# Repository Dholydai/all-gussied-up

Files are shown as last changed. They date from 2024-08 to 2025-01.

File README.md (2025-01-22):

# all-gussied-up

MAJOR CHANGES HAVE ARRIVED!

This repository will be removed shortly. Most variants have been moved to a new one called writerz-with-an-attitude.

I designed wonderfully sleek cases for my Dvorak 2024. All of my keyboard PCBs have been reworked to fit the new cases... except the TKL

The custom Cherry MX KiCad footprint library used is posted at https://github.com/Dholydai/mx-switch-custom

Please visit https://quixotickeyboards.com for more information.

Ronald Walker

23 Jul 2024 posted the left-hand and right-hand compact files. The trio is completed!

14 Aug 2024 posted the two-hand TKL files.

23 Oct 2024 changed the firmware files for the compact trio. Better edit key layout.

22 Jan 2025 closed out all folders except the TKL variant.

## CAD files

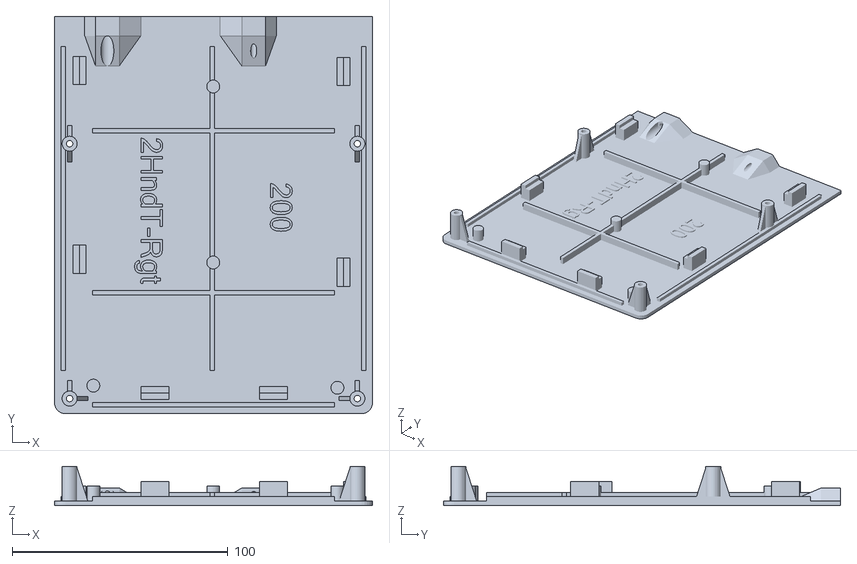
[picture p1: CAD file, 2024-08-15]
TKL2Hand/2HndTKLCase/stl/200ReduxBtmRgt.stl
147.2 x 184.0 x 18.2

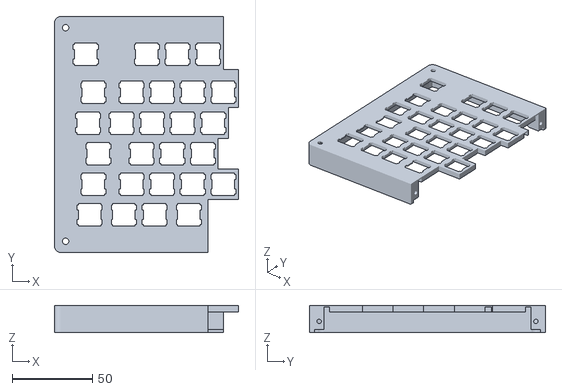
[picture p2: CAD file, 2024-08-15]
TKL2Hand/2HndTKLCase/stl/200ReduxTopLft.stl
114.8 x 147.1 x 17.0

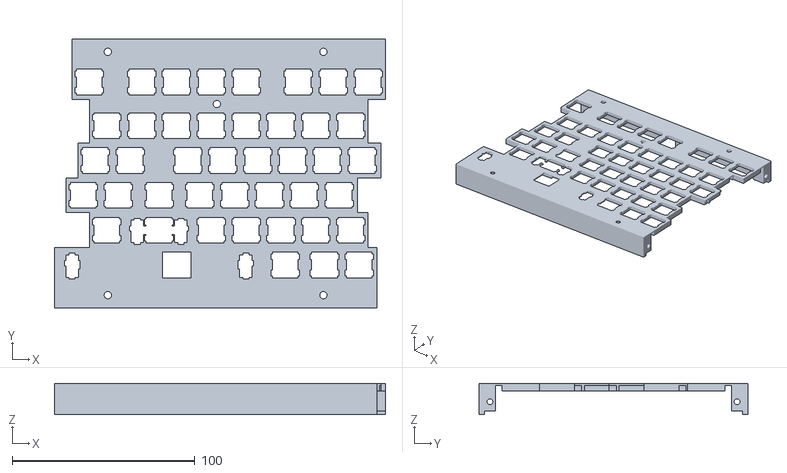
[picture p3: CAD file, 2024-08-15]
TKL2Hand/2HndTKLCase/stl/200ReduxTopMid.stl
181.0 x 147.1 x 17.0

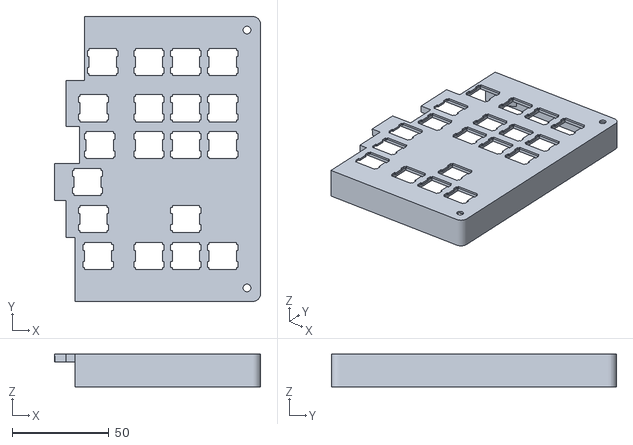
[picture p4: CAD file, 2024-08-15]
TKL2Hand/2HndTKLCase/stl/200ReduxTopRgt.stl
106.4 x 147.1 x 17.0

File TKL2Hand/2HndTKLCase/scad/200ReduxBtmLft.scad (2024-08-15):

//Created by Dholydai on 08 Aug 2024
//TXT
translate([109,62,0])
rotate([0,0,90])
linear_extrude(3)
text("2HndT-Lft",size=10,font="Microsoft Sans Serif");
translate([47,81,0])
rotate([0,0,90])
linear_extrude(3)
text("200",size=10,font="Microsoft Sans Serif");
//BASE
$fn=24;
//Deck and Towers
difference() {
    union() {
        translate([5,5,0])
            cube([137.25,179,2.2]);
        translate([5,0,0])
            cube([137.25,5,2.2]);
        translate([0,5,0])
            cube([5,179,2.2]);
        translate([142.25,5,0])
            cube([5,179,2.2]);    
        translate([5,5,0])
            cylinder(h=2.2,r1=5,r2=5);
        translate([142.25,5,0])
            cylinder(h=2.2,r1=5,r2=5);
        translate([7,7,0])
            cylinder(h=18.2,r1=3.5,r2=3.5);
        translate([7,125,0])
            cylinder(h=18.2,r1=3.5,r2=3.5);
        translate([140.25,125,0])
            cylinder(h=18.2,r1=3.5,r2=3.5);
        translate([140.25,7,0])
            cylinder(h=18.2,r1=3.5,r2=3.5);
    }
    translate([7,7,-4])
        cylinder(d=3,h=26);
    translate([7,125,-4])
        cylinder(d=3,h=26);
    translate([140.25,125,-4])
        cylinder(d=3,h=26);
    translate([140.25,7,-4])
        cylinder(d=3,h=26);
}
//Tower Supports
//Trigon0Y
translate([6,10.4,2.2])
    {TrigonPoints = [
    [0,0,0],//0
    [0,5,0],//1
    [0,0,15.5],//2
    [2,0,0],//3
    [2,5,0],//4
    [2,0,15.5]];//5
    TrigonFaces = [
    [0,1,2],//outside
    [0,3,4,1],//bottom
    [0,2,5,3],//top    
    [2,1,4,5],//back
    [3,5,4]];//inside
polyhedron(TrigonPoints,TrigonFaces);}
//Trigon0Yright
translate([10.4,6,2.2])
    {TrigonPoints = [
    [0,0,0],//0
    [5,0,0],//1
    [0,0,15.5],//2
    [0,2,0],//3
    [5,2,0],//4
    [0,2,15.5]]; //5
    TrigonFaces = [
    [0,2,1],//outside
    [0,1,4,3],//bottom
    [0,3,5,2],//top
    [1,2,5,4],//back
    [3,4,5]];//inside
polyhedron(TrigonPoints,TrigonFaces);}//
//Trigon1Y
translate([6,128.4,2.2])
    {TrigonPoints = [
    [0,0,0],//0
    [0,5,0],//1
    [0,0,15.5],//2
    [2,0,0],//3
    [2,5,0],//4
    [2,0,15.5]];//5
    TrigonFaces = [
    [0,1,2],//outside
    [0,3,4,1],//bottom
    [0,2,5,3],//top
    [2,1,4,5],//back
    [3,5,4]];//inside
polyhedron(TrigonPoints,TrigonFaces);}
//Trigon1Yrev
translate([6,116.6,2.2])
    {TrigonPoints = [
    [0,0,0],//0
    [0,5,0],//1
    [0,5,15.5],//2
    [2,0,0],//3
    [2,5,0],//4
    [2,5,15.5]]; //5
    TrigonFaces = [
    [0,1,2],//outside
    [0,3,4,1],//bottom
    [0,2,5,3],//top
    [1,4,5,2],//back
    [3,5,4]];//inside
polyhedron(TrigonPoints,TrigonFaces);}
//Trigon2Y
translate([139.25,128.4,2.2])
    {TrigonPoints = [
    [0,0,0],//0
    [0,5,0],//1
    [0,0,15.5],//2
    [2,0,0],//3
    [2,5,0],//4
    [2,0,15.5]]; //5
    TrigonFaces = [
    [0,1,2],//outside
    [0,3,4,1],//bottom
    [0,2,5,3],//top
    [2,1,4,5],//back
    [3,5,4]];//inside
polyhedron(TrigonPoints,TrigonFaces);}
//Trigon2Yrev
translate([139.25,116.6,2.2])
    {TrigonPoints = [
    [0,0,0],//0
    [0,5,0],//1
    [0,5,15.5],//2
    [2,0,0],//3
    [2,5,0],//4
    [2,5,15.5]]; //5
    TrigonFaces = [
    [0,1,2],//outside
    [0,3,4,1],//bottom
    [0,2,5,3],//top
    [1,4,5,2],//back
    [3,5,4]];//inside
polyhedron(TrigonPoints,TrigonFaces);}
//Trigon3Y
translate([139.25,10.4,2.2])
    {TrigonPoints = [
    [0,0,0],//0
    [0,5,0],//1
    [0,0,15.5],//2
    [2,0,0],//3
    [2,5,0],//4
    [2,0,15.5]]; //5
    TrigonFaces = [
    [0,1,2],//outside
    [0,3,4,1],//bottom
    [0,2,5,3],//top
    [2,1,4,5],//back
    [3,5,4]];//inside
polyhedron(TrigonPoints,TrigonFaces);}
//Trigon3Yleft
translate([131.85,6,2.2])
    {TrigonPoints = [
    [0,0,0],//0
    [5,0,0],//1
    [5,0,15.5],//2
    [0,2,0],//3
    [5,2,0],//4
    [5,2,15.5]]; //5
    TrigonFaces = [
    [0,2,1],//outside
    [0,1,4,3],//bottom
    [0,3,5,2],//top
    [1,2,5,4],//back
    [3,4,5]];//inside
polyhedron(TrigonPoints,TrigonFaces);}
//Ribs
translate([3.1,20,2.2])
    cube([2,150,2]);
translate([72,20,2.2])
    #cube([2,150,4]);
translate([142.15,20,2.2])
    #cube([2,150,2]);
translate([17.62,3.1,2.2])
    #cube([112,2,2]);
translate([17.62,130,2.2])
    #cube([112,2,4]);
translate([17.62,55,2.2])
    #cube([112,2,4]);
//Corner and Mid Supports
translate([16.5,13,2.2])
    cylinder(h=7,r1=3,r2=3);
translate([128,13,2.2])
    #cylinder(h=7,r1=3,r2=3);
translate([72.5,69,2.2])
    #cylinder(h=7,r1=3,r2=3);
translate([72.5,150,2.2])
    #cylinder(h=7,r1=3,r2=3);
//PCB Side
translate([40,6.6,2.2])
    cube([13,6,7]);
translate([40,6.6,9.2])
    #cube([13,3,2]);
translate([95,6.6,2.2])
    cube([13,6,7]);
translate([95,6.6,9.2])
    cube([13,3,2]);
//PCB Top Left
translate([10.5,64,2.2])
    cube([6,13,7]);
translate([10.5,64,9.2])
    cube([3,13,2]);
translate([10.5,149.5,2.2])
    cube([6,13,7]);
translate([10.5,149.5,9.2])
    cube([3,13,2]);
//PCB Bottom Left
translate([132.75,67,2.2])
    cube([6,8,7]);
translate([135.75,67,9.2])
    #cube([3,8,2]);
translate([132.5,161,2.2])
    cube([6,13,7]);
translate([135.75,161,9.2])
    #cube([3,13,2]);
//Mechanical Union
//Top Joint
difference() {
    translate([39.5,161,2.2])
        difference() {
            union() {   
                translate([10,14,0])
                    cube([11,9,6]);
//Right
polyhedron(points=[[21,14,0], [31,14,0], [31,23,0], [21,23,0], [21,14,6], [21,23,6]],
    faces=[[0,1,2,3],[1,4,5,2],[0,3,5,4],[0,4,1],[3,2,5]]
              );
//Left
polyhedron(points=[[5,14,0], [10,14,0], [10,23,0], [5,23,0], [10,14,6], [10,23,6]],
    faces=[[0,1,2,3],[1,4,5,2],[0,3,5,4],[0,4,1],[3,2,5]]
              );
//Flip                  0       1           2          3        4           5
polyhedron(points=[[10,0,0], [21,0,0], [21,14,0], [10,14,0], [10,14,6], [21,14,6]],
    faces=[[0,1,2,3],[5,4,3,2],[0,4,5,1],[0,3,4],[5,2,1]]
              );
polyhedron(points=[[21,14,0], [21,0,0], [31,14,0], [21,14,6]],
    faces=[[0,1,2],[0,2,3],[0,3,1],[1,3,2]]
              );
polyhedron(points=[[5,14,0], [10,14,0], [10,0,0], [10,14,6]],
    faces=[[0,2,1],[0,1,3],[1,2,3],[0,3,2]]
              );
    }
     translate([15.5,10,3]){
     rotate([-90,0,0])
        #cylinder(d=3.2,h=16);
        
        }
    translate([15.5,0,3]){
     rotate([-90,0,0])
       #cylinder(d=6,h=14);
        
        }
}
//Divets
translate([51.5,176,7.2])
    cylinder(h=3,r1=0,r2=4,center=false);
translate([51.5,181,7.2])
    cylinder(h=3,r1=1,r2=3.5,center=false);
}
//Bottom Joint
translate([107.25,161,2.2])
    difference() {
        union() {   
            translate([10,14,0])
                #cube([11,9,6]);
//Right
polyhedron(points=[[21,14,0], [26,14,0], [26,23,0], [21,23,0], [21,14,6], [21,23,6]],
    faces=[[0,1,2,3],[1,4,5,2],[0,3,5,4],[0,4,1],[3,2,5]]
              );
//Left
polyhedron(points=[[0,14,0], [10,14,0], [10,23,0], [0,23,0], [10,14,6], [10,23,6]],
    faces=[[0,1,2,3],[1,4,5,2],[0,3,5,4],[0,4,1],[3,2,5]]
              );
//Flip                  0       1           2          3        4           5
polyhedron(points=[[10,0,0], [21,0,0], [21,14,0], [10,14,0], [10,14,6], [21,14,6]],
    faces=[[0,1,2,3],[5,4,3,2],[0,4,5,1],[0,3,4],[5,2,1]]
              );
polyhedron(points=[[21,14,0], [21,0,0], [26,14,0], [21,14,6]],
    faces=[[0,1,2],[0,2,3],[0,3,1],[1,3,2]]
              );
polyhedron(points=[[0,14,0], [10,14,0], [10,0,0], [10,14,6]],
    faces=[[0,2,1],[0,1,3],[1,2,3],[0,3,2]]
              );
    }
     translate([15.5,2,3]){
     rotate([-90,0,0])
        #cylinder(d=2.8,h=24);
        
        }
    translate([15.5,-2,3]){
     rotate([-90,0,0])
       *cylinder(d=6,h=14);
        
        }
}    
//USB Ramp
translate([0,161,2.2])
polyhedron(points=[[0,13,0], [10,13,0], [10,23,0], [0,23,0], [10,13,2], [10,23,2]],
    faces=[[0,1,2,3],[1,4,5,2],[0,3,5,4],[0,4,1],[3,2,5]]
             );

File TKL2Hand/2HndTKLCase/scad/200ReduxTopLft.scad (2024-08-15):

// Generated by SolidPython 1.1.3 on 2024-08-09 04:07:28
// Modified by ;Dholydai 09Aug 2025
$fn = 32;


difference() {
	union() {
		translate(v = [0, 0, 16.4445000000]) {
			translate(v = [0, 133.0625000000, 0]) {
				translate(v = [10, 0, 0]) {
					difference() {
						union() {
							difference() {
								union() {
									union() {
										translate(v = [173.8312500000, 0, 0]) {
											translate(v = [0, -59.5312500000, 0]) {
												minkowski() {
													cube(center = true, size = [359.6625000000, 139.0625000000, 0.5555000000]);
													cylinder(center = true, h = 0.5555000000, r = 4);
												}
											}
										}
										translate(v = [0, -119.0625000000, 0]) {
											translate(v = [0, 0, -3.5555000000]) {
												difference() {
													translate(v = [-1.5000000000, 0, 0]) {
														translate(v = [0, -1.5000000000, 0]) {
															cube(size = [350.6625000000, 122.0625000000, 4.1110000000]);
														}
													}
													cube(size = [347.6625000000, 119.0625000000, 3.0000000000]);
												}
											}
										}
										translate(v = [0.0000000000, 0, 0]) {
											translate(v = [0, 0.0000000000, 0]) {
												union() {
													translate(v = [9.5250000000, 0, 0]) {
														translate(v = [0, -9.5250000000, 0]) {
															cube(center = true, size = [19.0500000000, 19.0500000000, 1.1110000000]);
														}
													}
													translate(v = [9.5250000000, 0, 0]) {
														translate(v = [0, -9.5250000000, 0]) {
															difference() {
																translate(v = [0, 0, -1.5000000000]) {
																	cube(center = true, size = [19.0500000000, 19.0500000000, 4.1110000000]);
																}
																translate(v = [0, 0, -1.5000000000]) {
																	cube(center = true, size = [17.5500000000, 17.5500000000, 6.0000000000]);
																}
															}
														}
													}
												}
											}
										}
										translate(v = [0.0000000000, 0, 0]) {
											translate(v = [0, -19.0500000000, 0]) {
												union() {
													translate(v = [9.5250000000, 0, 0]) {
														translate(v = [0, -9.5250000000, 0]) {
															cube(center = true, size = [19.0500000000, 19.0500000000, 1.1110000000]);
														}
													}
													translate(v = [9.5250000000, 0, 0]) {
														translate(v = [0, -9.5250000000, 0]) {
															difference() {
																translate(v = [0, 0, -1.5000000000]) {
																	cube(center = true, size = [19.0500000000, 19.0500000000, 4.1110000000]);
																}
																translate(v = [0, 0, -1.5000000000]) {
																	cube(center = true, size = [17.5500000000, 17.5500000000, 6.0000000000]);
																}
															}
														}
													}
												}
											}
										}
										translate(v = [0.0000000000, 0, 0]) {
											translate(v = [0, -38.1000000000, 0]) {
												union() {
													translate(v = [9.5250000000, 0, 0]) {
														translate(v = [0, -9.5250000000, 0]) {
															cube(center = true, size = [19.0500000000, 19.0500000000, 1.1110000000]);
														}
													}
													translate(v = [9.5250000000, 0, 0]) {
														translate(v = [0, -9.5250000000, 0]) {
															difference() {
																translate(v = [0, 0, -1.5000000000]) {
																	cube(center = true, size = [19.0500000000, 19.0500000000, 4.1110000000]);
																}
																translate(v = [0, 0, -1.5000000000]) {
																	cube(center = true, size = [17.5500000000, 17.5500000000, 6.0000000000]);
																}
															}
														}
													}
												}
											}
										}
										translate(v = [0.0000000000, 0, 0]) {
											translate(v = [0, -57.1500000000, 0]) {
												union() {
													translate(v = [9.5250000000, 0, 0]) {
														translate(v = [0, -9.5250000000, 0]) {
															cube(center = true, size = [19.0500000000, 19.0500000000, 1.1110000000]);
														}
													}
													translate(v = [9.5250000000, 0, 0]) {
														translate(v = [0, -9.5250000000, 0]) {
															difference() {
																translate(v = [0, 0, -1.5000000000]) {
																	cube(center = true, size = [19.0500000000, 19.0500000000, 4.1110000000]);
																}
																translate(v = [0, 0, -1.5000000000]) {
																	cube(center = true, size = [17.5500000000, 17.5500000000, 6.0000000000]);
																}
															}
														}
													}
												}
											}
										}
										translate(v = [0.0000000000, 0, 0]) {
											translate(v = [0, -76.2000000000, 0]) {
												union() {
													translate(v = [9.5250000000, 0, 0]) {
														translate(v = [0, -9.5250000000, 0]) {
															cube(center = true, size = [19.0500000000, 19.0500000000, 1.1110000000]);
														}
													}
													translate(v = [9.5250000000, 0, 0]) {
														translate(v = [0, -9.5250000000, 0]) {
															difference() {
																translate(v = [0, 0, -1.5000000000]) {
																	cube(center = true, size = [19.0500000000, 19.0500000000, 4.1110000000]);
																}
																translate(v = [0, 0, -1.5000000000]) {
																	cube(center = true, size = [17.5500000000, 17.5500000000, 6.0000000000]);
																}
															}
														}
													}
												}
											}
										}
										translate(v = [0.0000000000, 0, 0]) {
											translate(v = [0, -95.2500000000, 0]) {
												union() {
													translate(v = [9.5250000000, 0, 0]) {
														translate(v = [0, -9.5250000000, 0]) {
															cube(center = true, size = [19.0500000000, 19.0500000000, 1.1110000000]);
														}
													}
													translate(v = [9.5250000000, 0, 0]) {
														translate(v = [0, -9.5250000000, 0]) {
															difference() {
																translate(v = [0, 0, -1.5000000000]) {
																	cube(center = true, size = [19.0500000000, 19.0500000000, 4.1110000000]);
																}
																translate(v = [0, 0, -1.5000000000]) {
																	cube(center = true, size = [17.5500000000, 17.5500000000, 6.0000000000]);
																}
															}
														}
													}
												}
											}
										}
										translate(v = [0.0000000000, 0, 0]) {
											translate(v = [0, -114.3000000000, 0]) {
												union() {
													translate(v = [9.5250000000, 0, 0]) {
														translate(v = [0, -2.3812500000, 0]) {
															cube(center = true, size = [19.0500000000, 4.7625000000, 1.1110000000]);
														}
													}
													translate(v = [9.5250000000, 0, 0]) {
														translate(v = [0, -2.3812500000, 0]) {
															difference() {
																translate(v = [0, 0, -1.5000000000]) {
																	cube(center = true, size = [19.0500000000, 4.7625000000, 4.1110000000]);
																}
																translate(v = [0, 0, -1.5000000000]) {
																	cube(center = true, size = [17.5500000000, 3.2625000000, 6.0000000000]);
																}
															}
														}
													}
												}
											}
										}
										translate(v = [19.0500000000, 0, 0]) {
											translate(v = [0, 0.0000000000, 0]) {
												union() {
													translate(v = [9.5250000000, 0, 0]) {
														translate(v = [0, -9.5250000000, 0]) {
															cube(center = true, size = [19.0500000000, 19.0500000000, 1.1110000000]);
														}
													}
													translate(v = [9.5250000000, 0, 0]) {
														translate(v = [0, -9.5250000000, 0]) {
															difference() {
																translate(v = [0, 0, -1.5000000000]) {
																	cube(center = true, size = [19.0500000000, 19.0500000000, 4.1110000000]);
																}
																translate(v = [0, 0, -1.5000000000]) {
																	cube(center = true, size = [17.5500000000, 17.5500000000, 6.0000000000]);
																}
															}
														}
													}
												}
											}
										}
										translate(v = [19.0500000000, 0, 0]) {
											translate(v = [0, -19.0500000000, 0]) {
												union() {
													translate(v = [9.5250000000, 0, 0]) {
														translate(v = [0, -9.5250000000, 0]) {
															cube(center = true, size = [19.0500000000, 19.0500000000, 1.1110000000]);
														}
													}
													translate(v = [9.5250000000, 0, 0]) {
														translate(v = [0, -9.5250000000, 0]) {
															difference() {
																translate(v = [0, 0, -1.5000000000]) {
																	cube(center = true, size = [19.0500000000, 19.0500000000, 4.1110000000]);
																}
																translate(v = [0, 0, -1.5000000000]) {
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

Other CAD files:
TKL2Hand/2HndTKLCase/stl/200ReduxBtmLft.stl
TKL2Hand/2HndTKLCase/scad/200ReduxBtmRgt.scad
TKL2Hand/2HndTKLCase/scad/200ReduxTopMid.scad
TKL2Hand/2HndTKLCase/scad/200ReduxTopRgt.scad

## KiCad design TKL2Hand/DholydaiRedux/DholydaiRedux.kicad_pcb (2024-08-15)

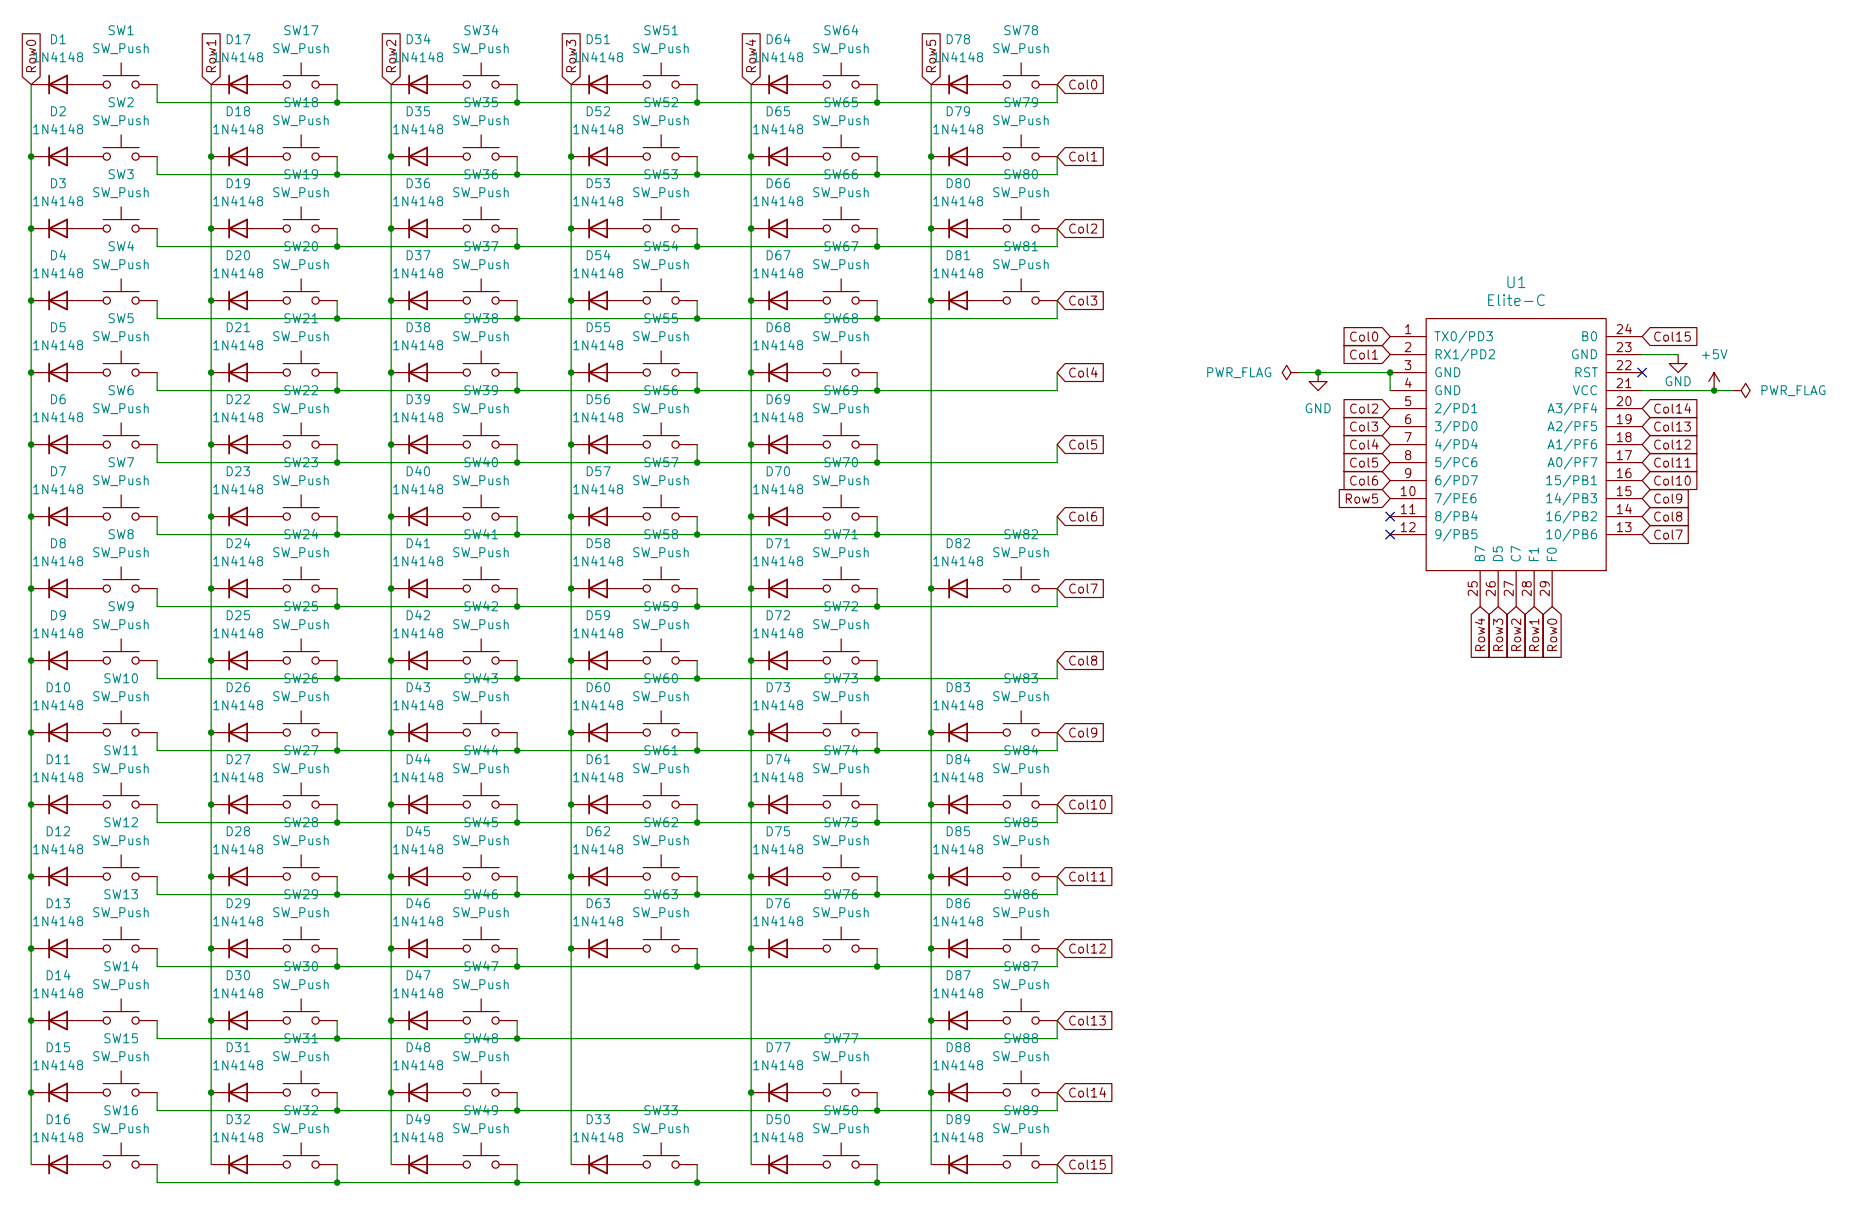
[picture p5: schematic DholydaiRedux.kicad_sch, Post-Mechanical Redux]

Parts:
D1, D2, D3, D4, D5, D6, D7, D8, D9, D10, D11, D12, D13, D14, D15, D16, D17, D18, D19, D20, D21, D22, D23, D24, D25, D26, D27, D28, D29, D30, D31, D32, D33, D34, D35, D36, D37, D38, D39, D40, D41, D42, D43, D44, D45, D46, D47, D48, D49, D50, D51, D52, D53, D54, D55, D56, D57, D58, D59, D60, D61, D62, D63, D64, D65, D66, D67, D68, D69, D70, D71, D72, D73, D74, D75, D76, D77, D78, D79, D80, D81, D82, D83, D84, D85, D86, D87, D88, D89: 1N4148; D_DO-35_SOD27_P7.62mm_Horizontal
SW1, SW2, SW3, SW4, SW5, SW6, SW7, SW8, SW9, SW10, SW11, SW12, SW13, SW14, SW15, SW16, SW18, SW19, SW20, SW21, SW22, SW23, SW24, SW25, SW26, SW27, SW28, SW29, SW31, SW32, SW33, SW35, SW36, SW37, SW38, SW39, SW40, SW41, SW42, SW43, SW44, SW45, SW46, SW48, SW49, SW50, SW52, SW53, SW54, SW55, SW56, SW58, SW59, SW60, SW61, SW62, SW65, SW66, SW67, SW68, SW69, SW71, SW72, SW73, SW74, SW75, SW77, SW79, SW80, SW84, SW85, SW87, SW88, SW89: SW_Push; SW_Cherry_MX_1.00u_PCB
SW17, SW30, SW64, SW76: SW_Push; SW_Cherry_MX_1.50u_PCB
SW34, SW47: SW_Push; SW_Cherry_MX_1.1666u_PCB
SW51, SW63: SW_Push; SW_Cherry_MX_1.8333u_PCB
SW57: SW_Push; SW_Cherry_MX_1.3333u_PCB
SW70: SW_Push; SW_Cherry_MX_2.00u_PCB
SW78, SW81, SW83, SW86: SW_Push; SW_Cherry_MX_1.25u_PCB
SW82: SW_Push; SW_Cherry_MX_6.00u_PCB_Stagger
U1: Elite-C

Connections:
+5V: U1.21 (VCC)
Col0: SW1.2, SW17.2, SW34.2, SW51.2, SW64.2, SW78.2, U1.1 (TX0/PD3)
Col1: SW2.2, SW18.2, SW35.2, SW52.2, SW65.2, SW79.2, U1.2 (RX1/PD2)
Col2: SW3.2, SW19.2, SW36.2, SW53.2, SW66.2, SW80.2, U1.5 (2/PD1)
Col3: SW4.2, SW20.2, SW37.2, SW54.2, SW67.2, SW81.2, U1.6 (3/PD0)
Col4: SW5.2, SW21.2, SW38.2, SW55.2, SW68.2, U1.7 (4/PD4)
Col5: SW6.2, SW22.2, SW39.2, SW56.2, SW69.2, U1.8 (5/PC6)
Col6: SW7.2, SW23.2, SW40.2, SW57.2, SW70.2, U1.9 (6/PD7)
Col7: SW8.2, SW24.2, SW41.2, SW58.2, SW71.2, SW82.2, U1.13 (10/PB6)
Col8: SW9.2, SW25.2, SW42.2, SW59.2, SW72.2, U1.14 (16/PB2)
Col9: SW10.2, SW26.2, SW43.2, SW60.2, SW73.2, SW83.2, U1.15 (14/PB3)
Col10: SW11.2, SW27.2, SW44.2, SW61.2, SW74.2, SW84.2, U1.16 (15/PB1)
Col11: SW12.2, SW28.2, SW45.2, SW62.2, SW75.2, SW85.2, U1.17 (A0/PF7)
Col12: SW13.2, SW29.2, SW46.2, SW63.2, SW76.2, SW86.2, U1.18 (A1/PF6)
Col13: SW14.2, SW30.2, SW47.2, SW87.2, U1.19 (A2/PF5)
Col14: SW15.2, SW31.2, SW48.2, SW77.2, SW88.2, U1.20 (A3/PF4)
Col15: SW16.2, SW32.2, SW33.2, SW49.2, SW50.2, SW89.2, U1.24 (B0)
GND: U1.3 (GND), U1.4 (GND), U1.23 (GND)
unnamed: D1.2 (A), SW1.1
unnamed: D2.2 (A), SW2.1
unnamed: D3.2 (A), SW3.1
unnamed: D4.2 (A), SW4.1
unnamed: D5.2 (A), SW5.1
unnamed: D6.2 (A), SW6.1
unnamed: D7.2 (A), SW7.1
unnamed: D8.2 (A), SW8.1
unnamed: D9.2 (A), SW9.1
unnamed: D10.2 (A), SW10.1
unnamed: D11.2 (A), SW11.1
unnamed: D12.2 (A), SW12.1
unnamed: D13.2 (A), SW13.1
unnamed: D14.2 (A), SW14.1
unnamed: D15.2 (A), SW15.1
unnamed: D16.2 (A), SW16.1
unnamed: D17.2 (A), SW17.1
unnamed: D18.2 (A), SW18.1
unnamed: D19.2 (A), SW19.1
unnamed: D20.2 (A), SW20.1
unnamed: D21.2 (A), SW21.1
unnamed: D22.2 (A), SW22.1
unnamed: D23.2 (A), SW23.1
unnamed: D24.2 (A), SW24.1
unnamed: D25.2 (A), SW25.1
unnamed: D26.2 (A), SW26.1
unnamed: D27.2 (A), SW27.1
unnamed: D28.2 (A), SW28.1
unnamed: D29.2 (A), SW29.1
unnamed: D30.2 (A), SW30.1
unnamed: D31.2 (A), SW31.1
unnamed: D32.2 (A), SW32.1
unnamed: D33.2 (A), SW33.1
unnamed: D34.2 (A), SW34.1
unnamed: D35.2 (A), SW35.1
unnamed: D36.2 (A), SW36.1
unnamed: D37.2 (A), SW37.1
unnamed: D38.2 (A), SW38.1
unnamed: D39.2 (A), SW39.1
unnamed: D40.2 (A), SW40.1
unnamed: D41.2 (A), SW41.1
unnamed: D42.2 (A), SW42.1
unnamed: D43.2 (A), SW43.1
unnamed: D44.2 (A), SW44.1
unnamed: D45.2 (A), SW45.1
unnamed: D46.2 (A), SW46.1
unnamed: D47.2 (A), SW47.1
unnamed: D48.2 (A), SW48.1
unnamed: D49.2 (A), SW49.1
unnamed: D50.2 (A), SW50.1
unnamed: D51.2 (A), SW51.1
unnamed: D52.2 (A), SW52.1
unnamed: D53.2 (A), SW53.1
unnamed: D54.2 (A), SW54.1
unnamed: D55.2 (A), SW55.1
unnamed: D56.2 (A), SW56.1
unnamed: D57.2 (A), SW57.1
unnamed: D58.2 (A), SW58.1
unnamed: D59.2 (A), SW59.1
unnamed: D60.2 (A), SW60.1
unnamed: D61.2 (A), SW61.1
unnamed: D62.2 (A), SW62.1
unnamed: D63.2 (A), SW63.1
unnamed: D64.2 (A), SW64.1
unnamed: D65.2 (A), SW65.1
unnamed: D66.2 (A), SW66.1
unnamed: D67.2 (A), SW67.1
unnamed: D68.2 (A), SW68.1
unnamed: D69.2 (A), SW69.1
unnamed: D70.2 (A), SW70.1
unnamed: D71.2 (A), SW71.1
unnamed: D72.2 (A), SW72.1
unnamed: D73.2 (A), SW73.1
unnamed: D74.2 (A), SW74.1
unnamed: D75.2 (A), SW75.1
unnamed: D76.2 (A), SW76.1
unnamed: D77.2 (A), SW77.1
unnamed: D78.2 (A), SW78.1
unnamed: D79.2 (A), SW79.1
unnamed: D80.2 (A), SW80.1
unnamed: D81.2 (A), SW81.1
unnamed: D82.2 (A), SW82.1
unnamed: D83.2 (A), SW83.1
unnamed: D84.2 (A), SW84.1
unnamed: D85.2 (A), SW85.1
unnamed: D86.2 (A), SW86.1
unnamed: D87.2 (A), SW87.1
unnamed: D88.2 (A), SW88.1
unnamed: D89.2 (A), SW89.1
Row0: D1.1 (K), D2.1 (K), D3.1 (K), D4.1 (K), D5.1 (K), D6.1 (K), D7.1 (K), D8.1 (K), D9.1 (K), D10.1 (K), D11.1 (K), D12.1 (K), D13.1 (K), D14.1 (K), D15.1 (K), D16.1 (K), U1.29 (F0)
Row1: D17.1 (K), D18.1 (K), D19.1 (K), D20.1 (K), D21.1 (K), D22.1 (K), D23.1 (K), D24.1 (K), D25.1 (K), D26.1 (K), D27.1 (K), D28.1 (K), D29.1 (K), D30.1 (K), D31.1 (K), D32.1 (K), U1.28 (F1)
Row2: D34.1 (K), D35.1 (K), D36.1 (K), D37.1 (K), D38.1 (K), D39.1 (K), D40.1 (K), D41.1 (K), D42.1 (K), D43.1 (K), D44.1 (K), D45.1 (K), D46.1 (K), D47.1 (K), D48.1 (K), D49.1 (K), U1.27 (C7)
Row3: D33.1 (K), D51.1 (K), D52.1 (K), D53.1 (K), D54.1 (K), D55.1 (K), D56.1 (K), D57.1 (K), D58.1 (K), D59.1 (K), D60.1 (K), D61.1 (K), D62.1 (K), D63.1 (K), U1.26 (D5)
Row4: D50.1 (K), D64.1 (K), D65.1 (K), D66.1 (K), D67.1 (K), D68.1 (K), D69.1 (K), D70.1 (K), D71.1 (K), D72.1 (K), D73.1 (K), D74.1 (K), D75.1 (K), D76.1 (K), D77.1 (K), U1.25 (B7)
Row5: D78.1 (K), D79.1 (K), D80.1 (K), D81.1 (K), D82.1 (K), D83.1 (K), D84.1 (K), D85.1 (K), D86.1 (K), D87.1 (K), D88.1 (K), D89.1 (K), U1.10 (7/PE6)

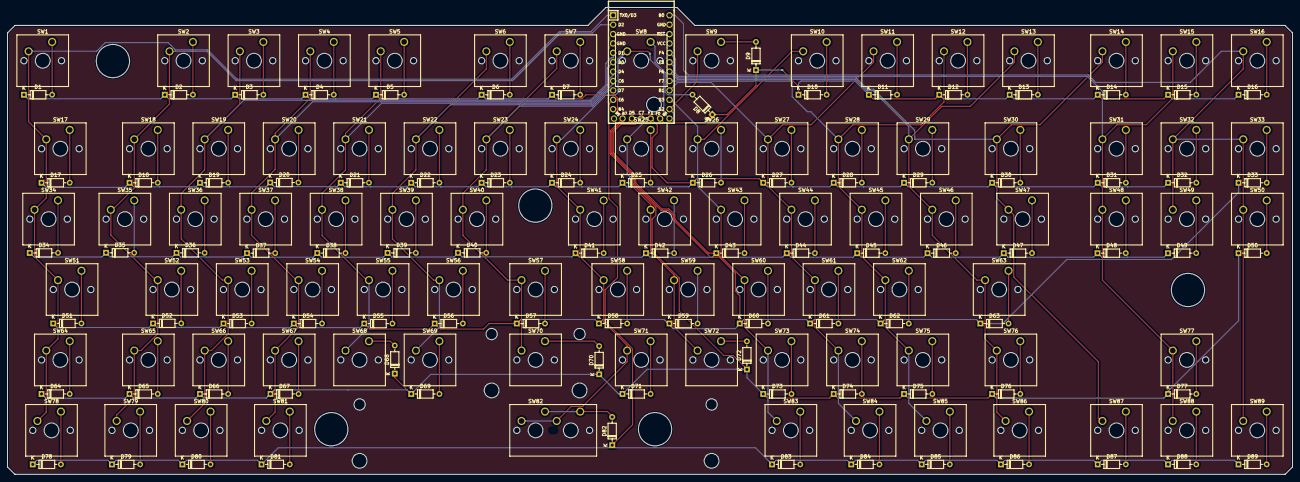
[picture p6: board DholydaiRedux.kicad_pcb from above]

Board: 2 copper layers, 347.7 x 126.3 mm, 179 parts (0 on the bottom side), 112 nets.

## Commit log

2024-06-23 3D Printing Files
    [200Cmp2hBtmLft-1.1.stl, 200Cmp2hBtmLft.scad, 200Cmp2hBtmRgt-1.1.stl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]
2024-06-23 Files for 3D printing the case
    [200Cmp2hBtmLft-1.1.stl, 200Cmp2hBtmLft.scad, 200Cmp2hBtmRgt-1.1.stl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]
2024-06-23 Files from the PCB design
    [DholydaiComp.kicad_pcb, DholydaiComp.kicad_sch]
2024-07-10 Improved tolerances on bottom files. Renamed all files.
    [200Comp2HndBtmLft.scad, 200Comp2HndBtmRgt.scad, 200Comp2HndTopLft.scad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]
2024-07-10 Renamed files with improved tolerances.
    [200Comp2HndBtmLft.scad, 200Comp2HndBtmRgt.scad, 200Comp2HndTopLft.scad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]
2024-07-10 Improved 3D print files
    [200Comp2HndBtmLft.stl, 200Comp2HndBtmRgt.stl, 200Comp2HndTopLft.stl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]
2024-07-10 Files for 3D printed keyboard cases
2024-07-23 OpenSCAD files from the PCB design
2024-07-23 Files from the keyboard case design
    [200Comp2HndBtmLft.scad, 200Comp2HndBtmRgt.scad, 200Comp2HndTopLft.scad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]
2024-07-23 Files to make the keyboard case
2024-07-23 Files to 3D print a case
    [200CompLeftBtmLft.stl, 200CompLeftBtmRgt.stl, 200CompLeftTopLft.stl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]
2024-07-23 Files to make a keyboard case
2024-07-23 Delete CompLeft-Hand/LeftHndCompCase/stl/qjk
    Files for 3D printing the case
2024-08-15 Files to print the keyboard case
2024-08-15 Files for QMK firmware install
    [DholydaiRedux.kicad_pcb, DholydaiRedux.kicad_sch]
